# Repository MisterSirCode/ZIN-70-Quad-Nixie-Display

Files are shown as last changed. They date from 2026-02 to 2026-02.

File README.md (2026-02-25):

# ZIN-70 Quad Nixie Display
 
### Important Notes

This is a four tube display built using Millclock ZIN-70 Nixie Tubes. This can be used to drive a clock, or just as a numeric display.

Please note that if you decide to use this diaply as a clock, it does not include colons.

### Components and Requirements

Supply:
* Any* 12V 500mA (or better) supply. DC 5.5mm Male Plug

Mechanical and Connectors:
* 1x Same Sky `PJ-063AH` DC 5.5mm Female Connector 
* 1x C&K Switches `DP62J12S202HQ` DPDT Slide Switch (Power Switch)
* 2x Same Sky `TS04-66-85-BK-100-SMT` SPST Button (Hour and Minute buttons)
* 2x Keystone Elec. `1291-66 ` 9V Battery connector

Tubes:
* 4x Millclock `ZIN-70` Nixie Tubes (Z5680M Pinout) - 170V ~5mA each
* 1x NE-2 5mm "Daytime" Indicator (I used a yellow phosphor Mercury/Argon tube)
* 1x NE-2 5mm "Nighttime" Indicator (I used a blue phosphor Mercury/Argon Tube)

Passives:
* 4x 6.8kR 1206(in) SMD Current-Limiting Power Resistors (Nixie Tubes)
* 8x 1kR 1206(in) SMD Current-Limiting Signal Resistors (Outputs)
* 4x 200kR 1206(in) SMD Current-Limiting Power Resistors (Indicator Swapper)
* 2x 100nF 1206(in) SMD Decoupling Capacitors
* 2x 1uF 1206(in) SMD Filter Capacitors
* 2x 10k 1206(in) SMD Filter Resistors

HV Boost Supply:
* 1x Omnixie `NCH8200HV` (12V to 170V 30mA)
    - Custom footprint. Only compatible with NCH8200V.

Driver:
* 1x Murata `OKI-78SR-5/1.5-W36-C` 12-5V DC-DC Converter 
    - Custom footprint for this device. Swap or remove as required
* 1x Murata `OKI-78SR-12/1.0-W36-C` 18-12V DC-DC Converter 
    - Custom footprint for this device. Swap or remove as required
* 1x WaveShare `RP2040-Tiny` devboard 
    - Custom footprint. Please swap for your driver. Only compatible with 23-pin 2.54mm pitch RP2040 tinies.
    - Buy directly from waveshare if you want to avoid incompatibility.

Registers and Chips:
* 1x Texas Instruments `CD40109BPWRE4` TSSOP-16 4bit 3V to 18V Level Converter
    - Configured for 3.3V to 12V conversion specifically for ESP32. Adjust Vcc and Vdd as required.
* 2x Microchip Tech. `HV5122` PQFP-44 32bit HV Registers (220V 100mA Drains)
    - Custom symbol/package configured.

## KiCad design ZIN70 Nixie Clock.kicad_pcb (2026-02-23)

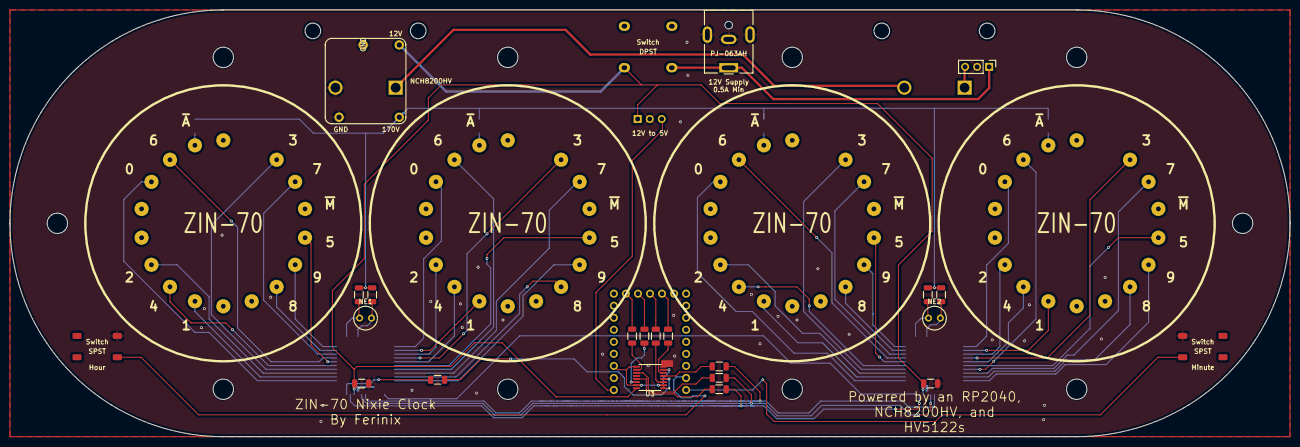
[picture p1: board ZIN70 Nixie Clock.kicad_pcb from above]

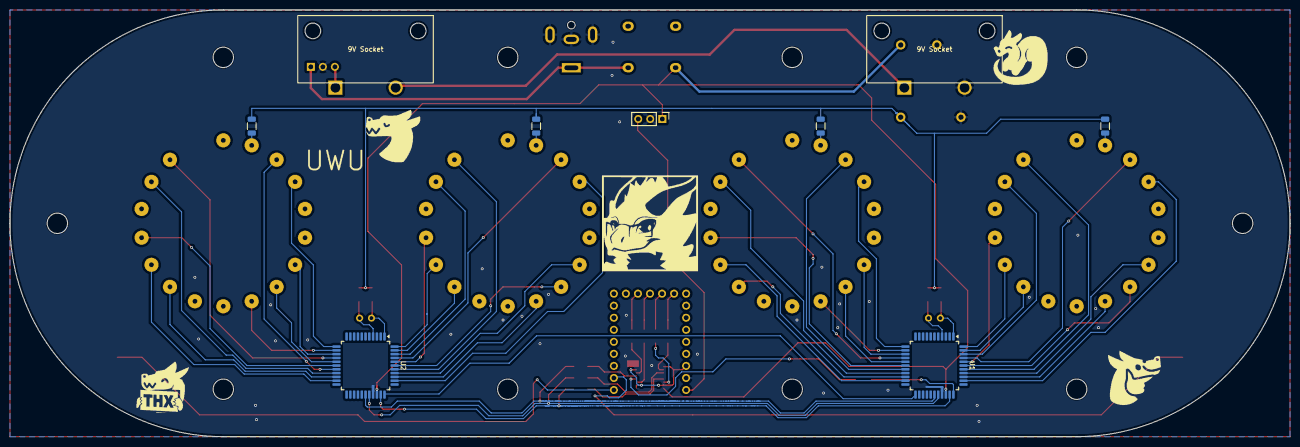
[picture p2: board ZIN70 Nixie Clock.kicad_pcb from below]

Board: 2 copper layers, 270.0 x 90.0 mm, 34 parts (8 on the bottom side), 65 nets.

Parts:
9V Socket, 9V Socket#2: 9V Socket Slim
C1, C2: 100nF; C_1206_3216Metric
NCH8200HV: NCH8200HV Through-Hole
NE1, NE2: NE-2; NE-2_5mm
NIX1, NIX2, NIX3, NIX4: ZIN-70; ZIN-70 Z5680M Pinout
PJ-063AH: BarrelJack_CUI_PJ-063AH_Horizontal
R1, R2, R3, R4: 6.8K; R_1206_3216Metric
R5, R6, R7, R8: 200K; R_1206_3216Metric
R9, R10, R11, R12, R13, R14, R15, R16: 1K; R_1206_3216Metric
Switch: TS04-66-85-BK-100-SMT SPST Button
Switch#2: DP62J12S202HQ DPDT Slide Switch
Switch#3: TS04-66-85-BK-100-SMT SPST Button
U1, U2: HV5122; PQFP-44_10x10mm_P0.8mm
U3: CD40109BPW; TSSOP-16_4.4x5mm_P0.65mm

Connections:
+3.3V: U3.1 (V_{CC}), U3.2 (ENABLE_A), U3.7 (ENABLE_B), U3.9 (ENABLE_C), U3.15 (ENABLE_D)
+12V: 9V Socket.2, 9V Socket#2.1, 9V Socket#2.2, C1.1, C2.1, PJ-063AH.1, U1.31 (VDD), U2.31 (VDD), U3.16 (V_{DD})
+170V: R1.1, R2.1, R3.1, R4.1, R5.2, R6.2, R7.2, R8.2
GND: 9V Socket.1, C1.2, C2.2, NCH8200HV.3, NCH8200HV.4, PJ-063AH.2, PJ-063AH.MP, Switch.1, Switch#3.3, U1.30 (GND), U2.30 (GND), U3.8 (V_{SS})
unnamed: NIX1.4 (0), U1.35 (HV1)
unnamed: NIX1.9 (1), U1.36 (HV2)
unnamed: NIX1.7 (2), U1.37 (HV3)
unnamed: NIX1.17 (3), U1.38 (HV4)
unnamed: NIX1.8 (4), U1.39 (HV5)
unnamed: NIX1.14 (5), U1.40 (HV6)
unnamed: NIX1.3 (6), U1.41 (HV7)
unnamed: NIX1.16 (7), U1.42 (HV8)
unnamed: NIX1.12 (8), U1.43 (HV9)
unnamed: NIX1.13 (9), U1.44 (HV10)
unnamed: NIX1.2 (~A), R1.2
unnamed: NIX2.4 (0), U1.12 (HV22)
unnamed: NIX2.9 (1), U1.13 (HV23)
unnamed: NIX2.7 (2), U1.14 (HV24)
unnamed: NIX2.17 (3), U1.15 (HV25)
unnamed: NIX2.8 (4), U1.16 (HV26)
unnamed: NIX2.14 (5), U1.17 (HV27)
unnamed: NIX2.3 (6), U1.18 (HV28)
unnamed: NIX2.16 (7), U1.19 (HV29)
unnamed: NIX2.12 (8), U1.20 (HV30)
unnamed: NIX2.13 (9), U1.21 (HV31)
unnamed: NIX2.2 (~A), R2.2
unnamed: NIX3.4 (0), U2.35 (HV1)
unnamed: NIX3.9 (1), U2.36 (HV2)
unnamed: NIX3.7 (2), U2.37 (HV3)
unnamed: NIX3.17 (3), U2.38 (HV4)
unnamed: NIX3.8 (4), U2.39 (HV5)
unnamed: NIX3.14 (5), U2.40 (HV6)
unnamed: NIX3.3 (6), U2.41 (HV7)
unnamed: NIX3.16 (7), U2.42 (HV8)
unnamed: NIX3.12 (8), U2.43 (HV9)
unnamed: NIX3.13 (9), U2.44 (HV10)
unnamed: NIX3.2 (~A), R3.2
unnamed: NIX4.4 (0), U2.12 (HV22)
unnamed: NIX4.9 (1), U2.13 (HV23)
unnamed: NIX4.7 (2), U2.14 (HV24)
unnamed: NIX4.17 (3), U2.15 (HV25)
unnamed: NIX4.8 (4), U2.16 (HV26)
unnamed: NIX4.14 (5), U2.17 (HV27)
unnamed: NIX4.3 (6), U2.18 (HV28)
unnamed: NIX4.16 (7), U2.19 (HV29)
unnamed: NIX4.12 (8), U2.20 (HV30)
unnamed: NIX4.13 (9), U2.21 (HV31)
unnamed: NIX4.2 (~A), R4.2
unnamed: R10.1, U1.29 (CLK), U2.29 (CLK)
unnamed: U1.23 (DATAOUT), U2.33 (DIN)
unnamed: R12.1, U1.33 (DIN)
unnamed: R5.1, U1.1 (HV11)
unnamed: R6.1, U1.4 (HV14)
unnamed: R9.1, U1.32 (STR), U2.32 (STR)
unnamed: R11.1, U1.28 (~OE), U2.28 (~OE)
unnamed: R7.1, U2.1 (HV11)
unnamed: R8.1, U2.4 (HV14)
unnamed: R13.1, U3.3 (A)
unnamed: R14.1, U3.6 (B)
unnamed: R15.1, U3.10 (C)
unnamed: R16.1, U3.14 (D)
unnamed: R12.2, U3.4 (E)
unnamed: R11.2, U3.5 (F)
unnamed: R10.2, U3.11 (G)
unnamed: R9.2, U3.13 (H)

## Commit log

2026-02-20 Update the clock with 5mm indicators
    [ZIN70 Nixie Clock-rounded.kicad_pcb, ZIN70 Nixie Clock.kicad_pcb, ZIN70 Nixie Clock.kicad_sch]
2026-02-23 Major changes to design
    [ZIN70 Nixie Clock-rounded.kicad_pcb, ZIN70 Nixie Clock.kicad_pcb, ZIN70 Nixie Clock.kicad_sch]
2026-02-25 Add debounce RC filters
2026-02-27 Last minute changes before printing
